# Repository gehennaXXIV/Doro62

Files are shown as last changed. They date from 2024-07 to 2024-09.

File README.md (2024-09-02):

# Doro62
***


[ZMK config](https://github.com/gehennaXXIV/zmk-config-Doro62) - It has a supporting json file for https://nickcoutsos.github.io/keymap-editor/ 

[QMK config](https://github.com/gehennaXXIV/qmk-config-GHN) - RP2040 Pro Micro w/ Vial support

***
## PARTS
| **COMPONENTS** |  Qty  |  Remarks |
| :--- 		 | :---: | :---  |
| Diodes 1N4148W (SMD)	 		 |  62 | SOD-123  |
| MX Switch Sockets				 |  62 | |
| 2U PCB-Mount Stabilizers |  03 | |
| Power Switch					 |  01 | MSK12C02 |
| Reset Switch 		 			 |  01 | MJTP1250, this is soldered to the bottom of the PCB |
| JST 2 PH Right Angle Jack	 |  01 | |
***
| **MCU** |  Qty  |  Remarks |
| :--- 		 | :---: | :---  |
| Low Profile MCU sockets |  04 |  Does not need to be expensive millmax sockets, the mcu socket footprint was modified to allow [sockets with thick pins to work](https://down-ph.img.susercontent.com/file/sg-11134201-7qvco-ley7fi4ef44v33)
| Mill Max Pins					 |  48 |  Mouser 3320-0-00-15-00-00-03-0, or a cheaper one, harvested gold pins 5pin RGB header (just snip off the plastic parts)
| Nice Nanos |  01 |  or NRF52840
| Li-Po Battery |  01 |  TAKE NOTE OF THE POLARITY BEFORE PLUGGING IT IN [Here's a tutorial on how to change the polarity.](https://www.youtube.com/watch?v=za-azgbZor8)

***
| **CASE** |  Qty  |  Remarks |
| :--- 		 | :---: | :---  |
| [Acrylic Case](/Case/) |  01 | maybe a 3DP one soon, but I'm very content with the acrylic case. LMK if you create one! |
| M2 8mm Wafer Head Screws		 |  24 | If you want to increase the distance from plate to top of case, might need to increase the length of the screws as well.
| M2 12mm Round Standoff Spacer |  12 |  Or 11 if it's portruding / giving plate a slight gap |
| Rubber Feet					 |  08 | Currently the keyboard lays flat, I've yet to design a base layer for angled feet |

***
## FOOTPRINTS USED
* https://github.com/ebastler/marbastlib
* https://github.com/joe-scotto/scottokeebs
* https://github.com/GEIGEIGEIST/KLOR
* https://github.com/50an6xy06r6n/keyboard_reversible.pretty

***
Please note that while this keyboard is provided as open-source, I am not liable for any issues, malfunctions, or other problems that may arise from its use. The keyboard is provided "as-is," and I make no warranties or guarantees regarding its performance or functionality. Use at your own risk.

This is my first take at creating a keyboard from scratch, there's obviously alot of things that could've been done better. I will be redesigning this board in the future.

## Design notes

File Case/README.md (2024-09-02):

4th and 5th layer's **thickness** are interchangeable. I recommend getting Clear Acrylic for the first four layers (from bottom) amd get a 4.5mm Clear Matte / Frosted Acrylic Top to also help reduce fingerprints.

If you need bottom clearance for bigger batteries, you can add another middle layer, how tall the layer is up to you, just be sure to also add the length to your standoffs.

If you are building a non ZMK (no battery clearance needed, on/off switch not soldered) build, I recommend a 1x 5mm 2 - bottom, and 1x 5mm middle (instead of 2x, significantly decreasing keyboard height, you would only be using 10mm).

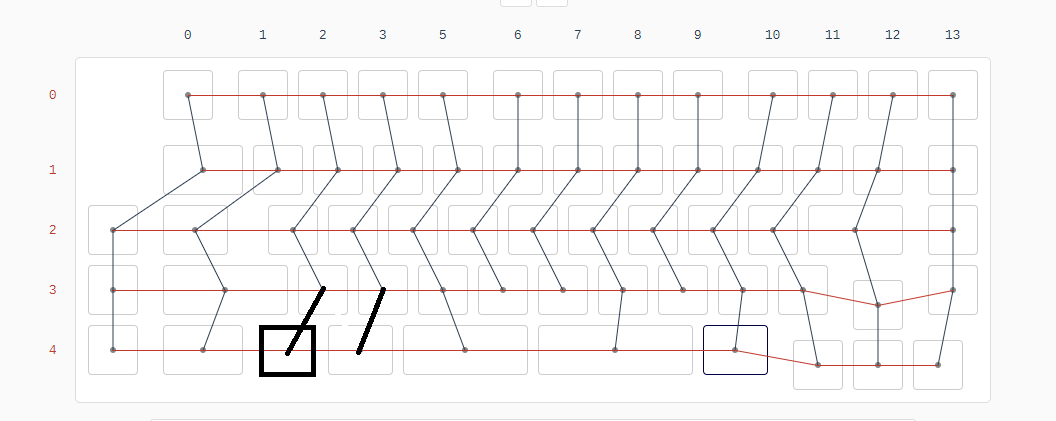
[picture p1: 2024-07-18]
Kicad/matrix.png

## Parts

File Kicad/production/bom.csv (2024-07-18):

Designator | Footprint | Quantity | Value | LCSC Part #
BT1 | JST_PH | 1 | Battery
BT2 | custombatteryconnector_small | 1 | Battery
D1, D10, D11, D12, D13, D14, D15, D16, D17, D18, D19, D2, D20, D21, D22, D23, D24, D25, D26, D27, D28, D29, D3, D30, D31, D32, D33, D34, D35, D36, D37, D38, D39, D4, D40, D41, D42, D43, D44, D45, D46, D47, D48, D49, D5, D50, D51, D52, D53, D54, D55, D56, D57, D58, D59, D6, D60, D61, D62, D7, D8, D9 | Diode_SOD123_SMD | 62 | D
PWR1 | Switch_MSK12C02 | 1 | SW_DPDT_x2
RST1 | Button_MJTP1250 | 1 | SW_Push_45deg
S1, S2 | STAB_MX_2.25u | 2 | MX_stab
S3 | STAB_MX_2.75u | 1 | MX_stab
SW1, SW10, SW11, SW12, SW13, SW15, SW16, SW17, SW18, SW19, SW2, SW20, SW21, SW22, SW23, SW24, SW25, SW26, SW27, SW29, SW3, SW30, SW31, SW32, SW33, SW34, SW35, SW36, SW37, SW39, SW4, SW40, SW42, SW43, SW44, SW45, SW46, SW47, SW48, SW49, SW5, SW50, SW51, SW52, SW53, SW55, SW6, SW60, SW61, SW62, SW7, SW8, SW9 | MX 1U | 53 | SW_Push_45deg
SW14, SW54 | MX 1.5U | 2 | SW_Push_45deg
SW28 | MX 1.75 STP 1.25 | 1 | SW_Push_45deg
SW38 | MX 1.75U | 1 | SW_Push_45deg
SW41, SW57 | MX 2.25U | 2 | SW_Push_45deg
SW56, SW59 | MX 1.25U | 2 | SW_Push_45deg
SW58 | MX 2.75U | 1 | SW_Push_45deg

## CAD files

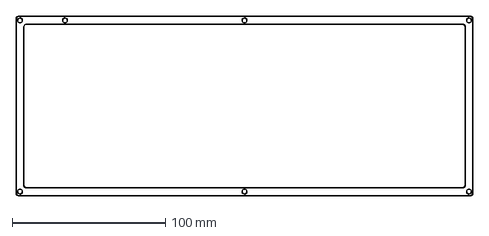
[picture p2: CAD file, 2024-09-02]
Case/2 - bottom - 2mm.dxf
297.7 x 116.7 mm

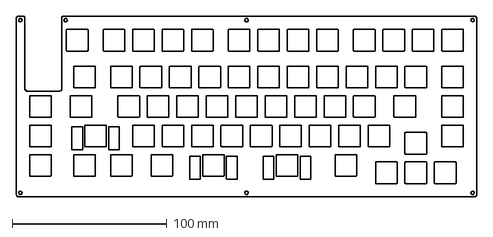
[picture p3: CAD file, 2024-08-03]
Kicad/plate/plate.dxf
297.7 x 116.7 mm

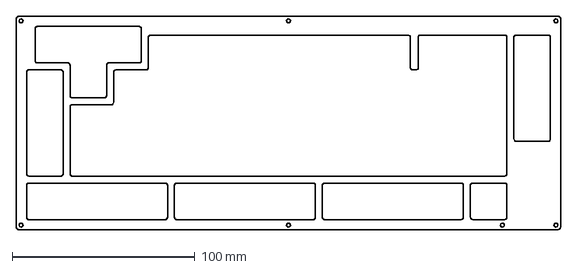
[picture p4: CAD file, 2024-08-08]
Case/5 - top - 3mm.dxf
297.7 x 116.7 mm

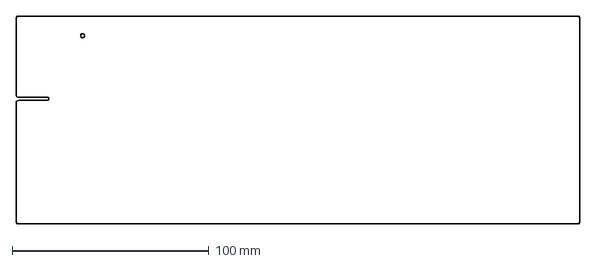
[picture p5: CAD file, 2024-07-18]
Kicad/plate/pcb cutout.dxf
286.7 x 105.7 mm

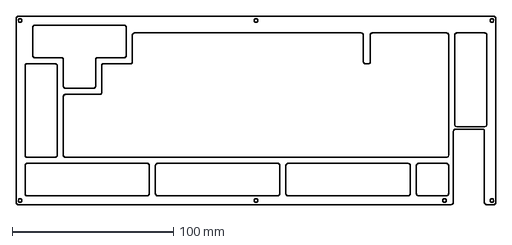
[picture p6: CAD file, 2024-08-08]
Case/4 - top middle - 4.5mm.dxf
297.7 x 116.7 mm

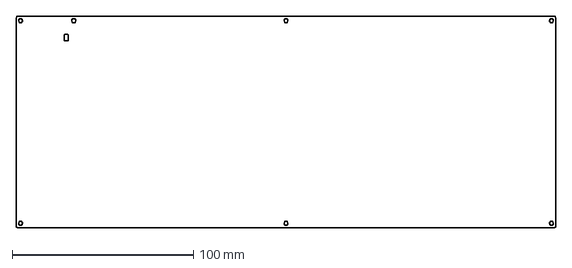
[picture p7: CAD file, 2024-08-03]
Case/1 - base - 3mm.dxf
297.7 x 116.7 mm

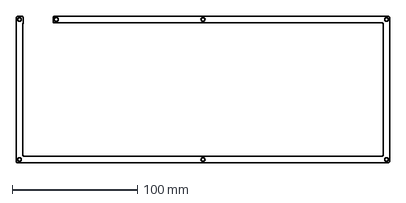
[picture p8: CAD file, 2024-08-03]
Case/3 - middle - 5mm - 2pcs.dxf
297.7 x 116.7 mm

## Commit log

2024-07-18 base
    v1
    [GHN626.kicad_sch, bom.csv, designators.csv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]
2024-09-02 docs update
    [2 - bottom - 2mm.dxf, 3 - middle - 5mm - 2pcs.dxf]
